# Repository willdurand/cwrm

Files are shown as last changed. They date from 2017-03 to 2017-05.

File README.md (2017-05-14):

Camera WiFi Remote Module
=========================



CWRM stands for _Camera WiFi Remote Module_. It is a ESP8266-based device that
allows to trigger the focus/shutter of a camera _via_ WiFI. It is in **early stage**
but it works with my Canon camera™.

<p align="center">
    
</p>

## Schematic

<p align="center">
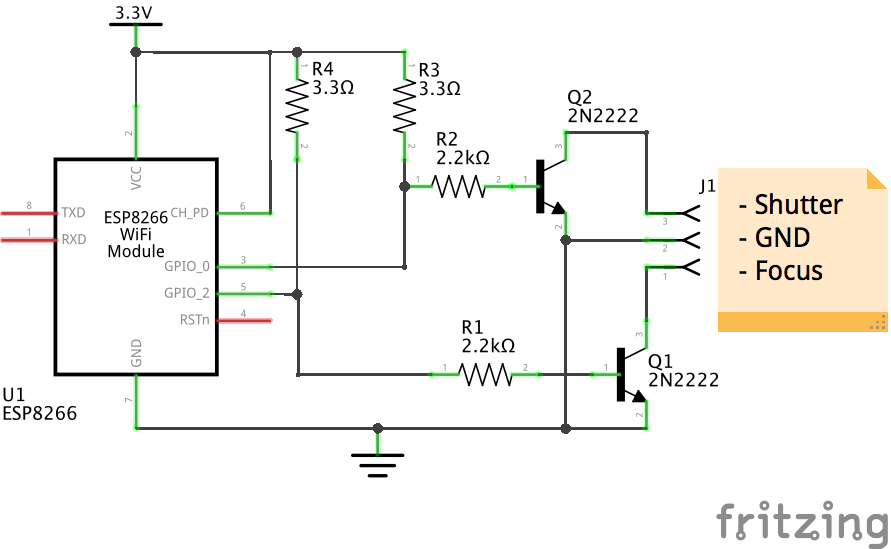
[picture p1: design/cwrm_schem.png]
    
</p>

### Parts

- 1 x ESP8266-01 (_U1_)
- 2 x 2.2k ohms (_R1_ and _R2_)
- 2 x 3.3k ohms (_R3_ and _R4_)
- 2 x 2N2222 (_Q1_ and _Q2_)
- 2.5mm male stereo plug (connected to _J1_, for Canon cameras)
- 3.3V power supply (like 2 AAA batteries)

## Case

A STL file is provided to 3D-print a case for this module. It costs ~20 euros
on Shapeways.

<p align="center">
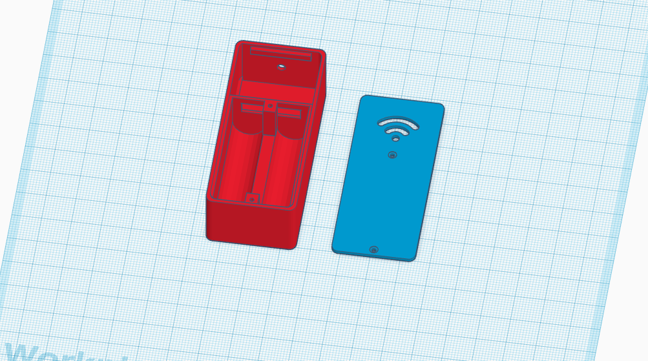
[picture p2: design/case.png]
    
</p>

## Software

The module creates its own WiFi network, and then acts as a captive portal,
redirecting everything to `192.168.10.1`. A simplistic web page is served to
control the camera.

<p align="center">
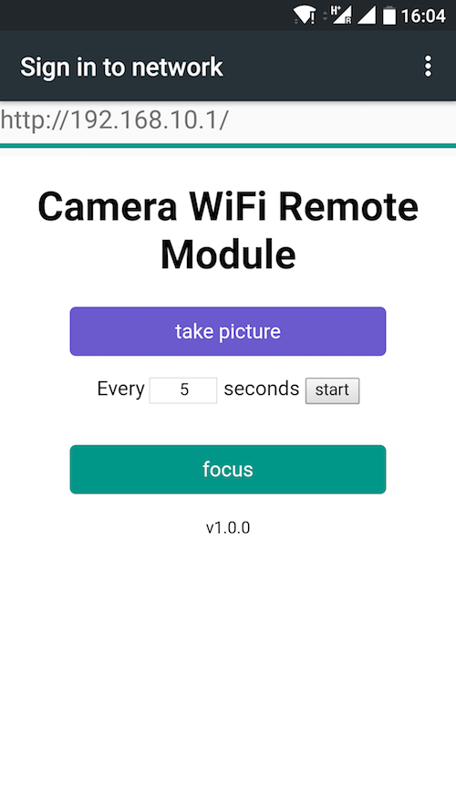
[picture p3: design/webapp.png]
    
</p>

### Development

The source code can be found in the `cwrm/` folder (Arduino IDE requires the
same name for both the main sketch and its directory). You can compile the
firmware using `make` (recommended):

    $ make clean
    $ make

By default, it is compiled for release purpose. You can also compile a debug
version with:

    $ make debug

You will need [html-minifier](https://github.com/kangax/html-minifier) installed
to compile the HTML code and generate the `cwrm/cwrm_generated.h` file:

    $ npm install html-minifier -g
    $ make compile-html

This project uses the following libraries/tools:

- AJAX lib: https://github.com/yanatan16/nanoajax
- Makefile: https://github.com/plerup/makeEspArduino
- CI build: https://github.com/adafruit/travis-ci-arduino

## Similar projects

- https://guillermoamaral.com/read/canon-wifimote/

## License

CWRM is released under the MIT License. See the bundled LICENSE file for
details.

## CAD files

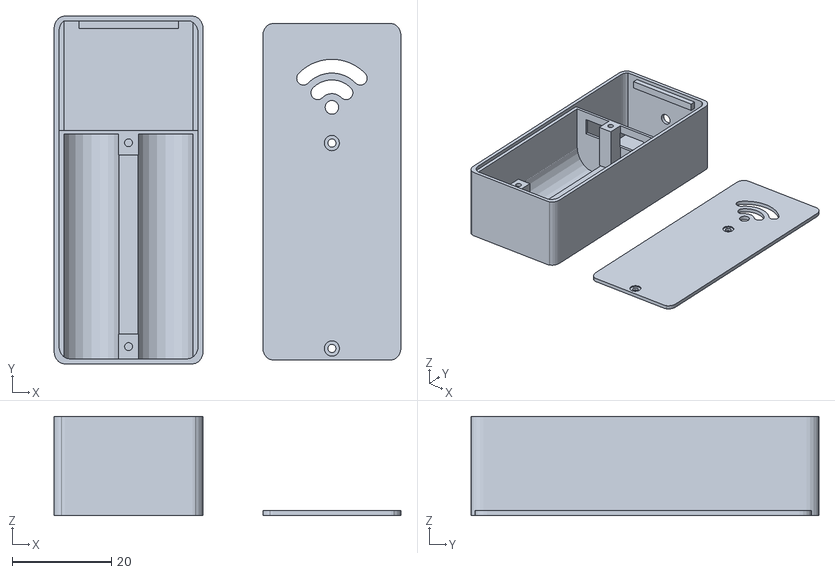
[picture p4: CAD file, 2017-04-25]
design/case.stl
69.8 x 70.0 x 20.0

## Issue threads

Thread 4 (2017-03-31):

Add pull-up resistors for GPIO0 et GPIO2

willdurand, 2017-03-31:
It was impossible to start the WiFi module with the current schematic assembled on a protoboard... `GPIO0` on the ESP8266 needs to be `HIGH`, otherwise it starts the serial programming mode (flash mode). According to the spec, GPIO2 should be `HIGH` too. I guess it worked well on the breadboard because pins were floating...

I fixed the current design by adding two pull-up resistors 3.3k for each GPIO. Because I only have NPN transistors, I did not update anything else. The main problem is that on boot, GPIOs are (input) `HIGH`, then turned (output) `LOW`. It triggers both the shutter and the focus for a few milliseconds, which might be a problem when plugged on the camera. Having PNP transistors would help mitigate this (shutter/focus would become active low).

willdurand, 2017-03-31:
Looks like it is what I need: https://electronics.stackexchange.com/questions/30238/how-to-invert-a-digital-signal.

willdurand, 2017-03-31:
Also, this explains a few things related to this issue http://www.esp8266.com/viewtopic.php?f=13&t=3718

willdurand, 2017-03-31:
cf. https://github.com/willdurand/cwrm/commit/95c2102b0f92377a56729e26c2279c4153dad2d9

willdurand, 2017-04-01:
> It triggers both the shutter and the focus for a few milliseconds, which might be a problem when plugged on the camera

It is not a problem apparently. I tried and it works. Sure it takes a picture but no problem. Let's close this issue so far and KISS.

Closed 2017-04-01.

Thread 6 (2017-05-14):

Add a power switch

willdurand, 2017-05-14:
I fixed the issue by adding a switch button on the second proto, but it makes sense to actually think about this stuff...

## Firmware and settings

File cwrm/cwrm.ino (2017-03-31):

#include <ESP8266WiFi.h>         //https://github.com/esp8266/Arduino
#include <DNSServer.h>
#include <ESP8266WebServer.h>
#include "cwrm_generated.h"

#define FOCUS_PIN     2
#define SHUTTER_PIN   0
#define FOCUS_DELAY   800
#define SHUTTER_DELAY 1200
#define WEB_PORT      80
#define DNS_PORT      53
#define AP_PASSWORD   "LetMeJoin"

#ifdef DEBUG
#define DEBUG_PRINT(message) Serial.println(message)
#else
#define DEBUG_PRINT(message)
#endif

// prototypes
void setup();
void loop();
void indexAction();
void redirectTo(String);
void triggerFocus();
void triggerShutter();

// global vars
IPAddress apIP(192, 168, 10, 1);
ESP8266WebServer webServer(WEB_PORT);
DNSServer dnsServer;

void setup() {
  pinMode(FOCUS_PIN, OUTPUT);
  pinMode(SHUTTER_PIN, OUTPUT);
  digitalWrite(FOCUS_PIN, LOW);
  digitalWrite(SHUTTER_PIN, LOW);

#ifdef DEBUG
  Serial.begin(115200); // open serial
#endif

  WiFi.mode(WIFI_AP);
  WiFi.softAPConfig(apIP, apIP, IPAddress(255, 255, 255, 0));
  WiFi.softAP(AP_NAME, AP_PASSWORD);

  // if DNSServer is started with "*" for domain name, it will reply with
  // provided IP to all DNS request
  dnsServer.start(DNS_PORT, "*", apIP);

  webServer.on("/", HTTP_GET, indexAction);
  webServer.on("/trigger/shutter", HTTP_POST, triggerShutter);
  webServer.on("/trigger/focus", HTTP_POST, triggerFocus);
  webServer.onNotFound([]() {
    redirectTo("/");
  });
  webServer.begin();
}

void loop() {
  dnsServer.processNextRequest();
  webServer.handleClient();
}

void indexAction() {
  webServer.send(200, "text/html", indexHTML);
}

void redirectTo(String path) {
  webServer.sendHeader("Location", "http://" + apIP.toString() + path);
  webServer.send(302);
}

void triggerFocus() {
  redirectTo("/");

  DEBUG_PRINT("Focus: start");
  digitalWrite(FOCUS_PIN, HIGH);
  delay(FOCUS_DELAY);
  DEBUG_PRINT("Focus: stop");
  digitalWrite(FOCUS_PIN, LOW);
}

void triggerShutter() {
  redirectTo("/");

  DEBUG_PRINT("Shutter: start");
  digitalWrite(SHUTTER_PIN, HIGH);
  delay(SHUTTER_DELAY);
  DEBUG_PRINT("Shutter: stop");
  digitalWrite(SHUTTER_PIN, LOW);
}

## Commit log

2017-03-24 Add Fritzing design
    [cwrm.fzz]
2017-03-27 Conditional compilation with DEBUG
    Fix #2
    [cwrm.ino]
2017-03-27 Add style to active buttons
2017-03-31 Synchronize schema with code
    [cwrm.fzz]
2017-03-31 Add pull-up resistors
    [cwrm.fzz]
2017-04-03 Reduce PCB size
    [cwrm.fzz]
2017-04-03 Add STL file containing the case
    [case.stl]
2017-04-04 Update case (STL)
    [case.stl]
2017-04-05 Rename Fritzing file
    [pcb.fzz]
2017-04-06 Update case model
    [case.stl]
2017-04-25 Fix problems with first case proto
    [case.stl]
2017-04-25 Add play for case
    [case.stl]
2017-05-14 Add case image
